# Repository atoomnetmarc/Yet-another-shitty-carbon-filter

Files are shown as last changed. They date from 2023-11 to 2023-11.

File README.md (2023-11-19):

Voron Trident, mounted lower left on the 2020 extrusion:
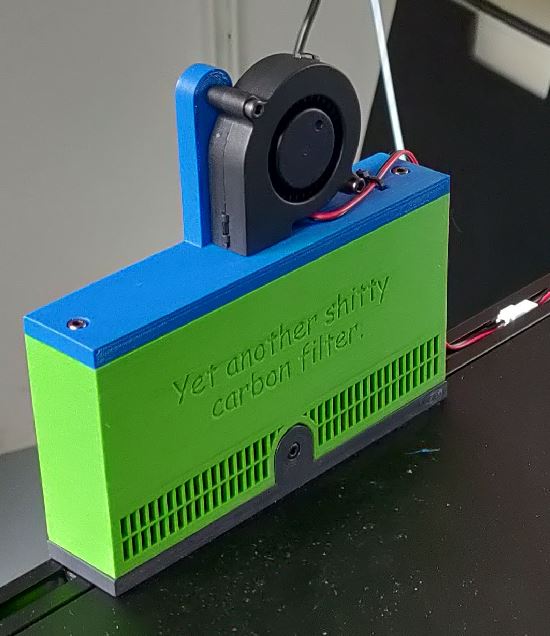
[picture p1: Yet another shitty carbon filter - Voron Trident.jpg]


Ultimaker 2, mounted lower right on 2 preexisting holes on the bottom plate:
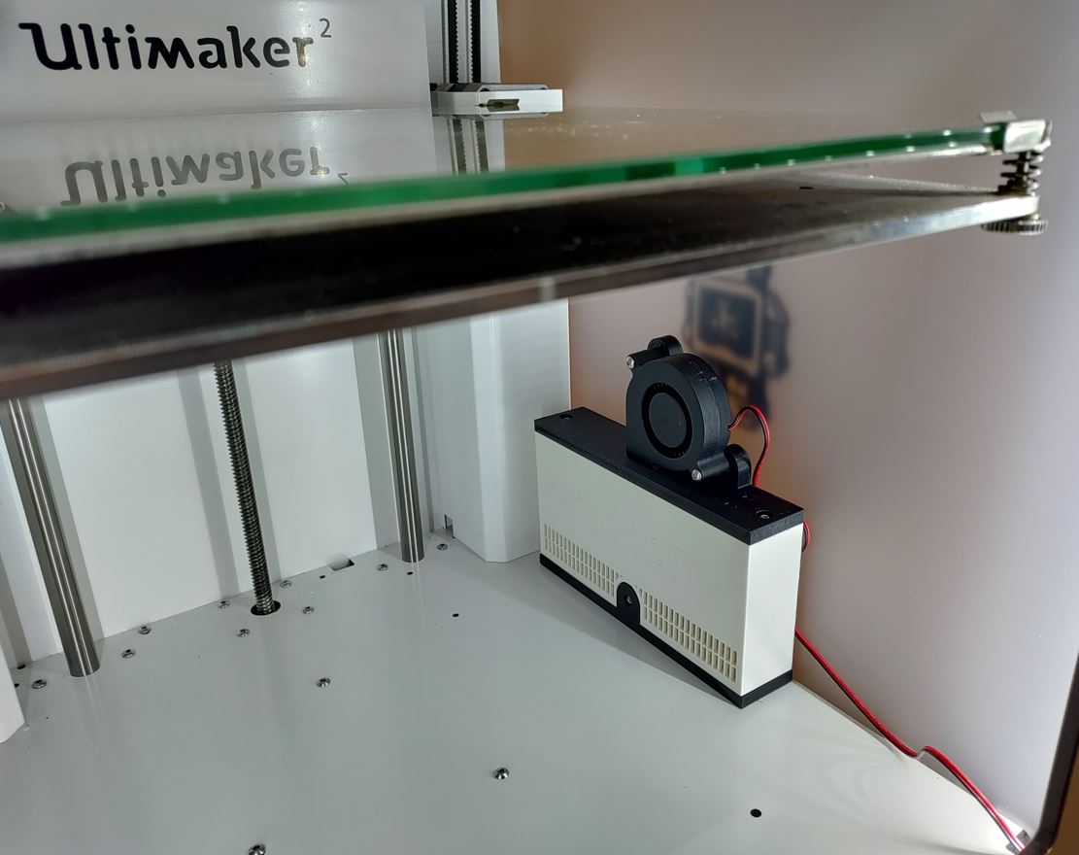
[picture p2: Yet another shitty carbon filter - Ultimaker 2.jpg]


# Why yet another design?

I tried printing the famous [Nevermore Micro V6](https://github.com/nevermore3d/Nevermore_Micro), it ended up in frustration with parts that broke multiple times during assembly (jalousie) or did not fit (lid). I decided to design my own shitty carbon filter.

# Dimensions

I designed this air filter to be used standing up on the lower bottom side of my Voron V0, Voron Trident and Ultimaker 2.

# Print and assembly instructions

Print in a material that withstands the temperature at which the filter will be used. I printed mine in ASA. No supports needed. If you have a color theme on your printer you may print the body in the base color and the mount and lid in the accent color. For the Ultimaker you could print the body in white and the other parts in black.

Print one of the mounting brackets:

- `Yet another shitty carbon filter - 1515 mount.stl`
- `Yet another shitty carbon filter - 2020 mount.stl`
- `Yet another shitty carbon filter - Ultimaker 2 mount.stl`

The 2 screw holes for the 1515 and 2020 mount that connect to the extrusion will fit M3x8 (FHCS, BHCS, pan head). Use M3 t-nut or similar for in your aluminium extrusion.

The [Ultimaker 2 mount needs 2 heat set inserts](Yet%20another%20shitty%20carbon%20filter%20-%20Ultimaker%202%20mount%20-%20showing%20heat%20set%20inserts.jpg). Then screw with 2x M3x10 (or M3x12) from [below the bottom panel on the lower right](Yet%20another%20shitty%20carbon%20filter%20-%20Ultimaker%202%20mount%20-%20mounted.jpg).

Print `Yet another shitty carbon filter - body.stl`. You may want to use a brim if lifting is a problem. Slight lifting is not a problem. Do you have a multi material unit or multi extruder? Then print `Yet another shitty carbon filter - body - text (MMU).stl` at the same time as the body but configure it to print in the accent color.

Melt 2 heat set inserts M3x5x4mm into the holes they fit in:

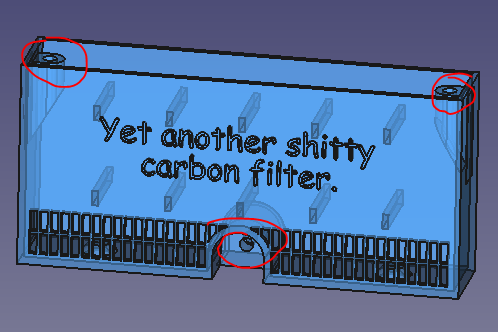
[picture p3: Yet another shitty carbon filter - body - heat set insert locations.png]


Use a single M3x16 (up to M3x27) to screw the mount to the body:

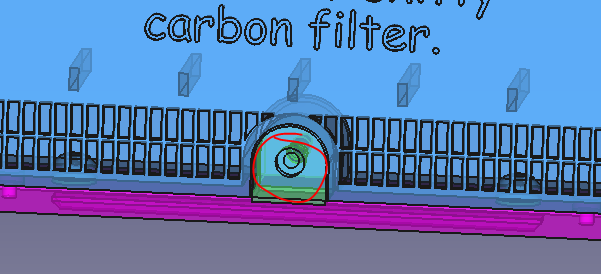
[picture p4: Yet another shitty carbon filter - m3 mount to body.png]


Print `Yet another shitty carbon filter - lid with 5015 fan.stl`.

Melt 2 heat set inserts M3x5x4mm into the holes they fit in:
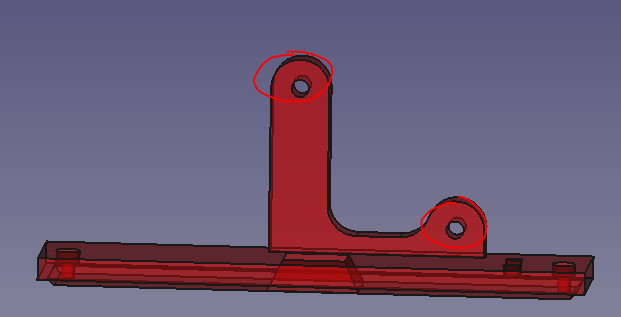
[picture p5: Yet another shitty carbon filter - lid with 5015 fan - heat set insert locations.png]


You can use 2 M3x8 (up to M3x65) screws to mount the lid to the body. Use 2 M3x20 (up to M3x22) to mount a 5015 blower fan to the lid.

# Electronics

Use your skills to connect the 5015 blower fan to whatever fitting power source. On the Voron Trident I used a 24V 5015 blower fan connected to the 3d-printer motherboard. I added an inline connector for easy disassembly. I then configured it in klipper as a `controller_fan` like this:

```ini
[controller_fan carbon_filter]
##  yet another shitty carbon filter - FAN3
pin: PD13
max_power: 1.0
shutdown_speed: 0.0
kick_start_time: 5.0
heater: extruder
fan_speed: 0.75
idle_timeout: 900
```

Customize `pin` to the real pin you use.

For the Ultimaker 2 3d printer you are on your own. I have modified mine with a custom motherboard so I cannot help you with yours. However, you could possibly use the second heater output. Maybe the simplest solution is to use a physical switch connected to the 24V power supply behind the relay on the board.

There is a slot in the lid to thread a ty-rap through, use it to add strain relief to for the wires to the fan:
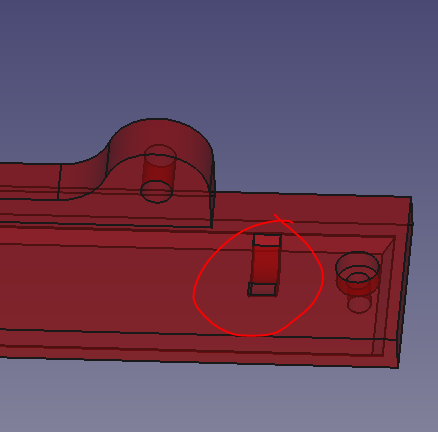
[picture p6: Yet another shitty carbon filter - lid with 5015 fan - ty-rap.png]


# Activated carbon

The ventilation holes at the air outlet on the body where designed to mostly contain 4mm activated carbon. The holes are 2mm higher than the bottom of the body so that carbon dust can settle there.

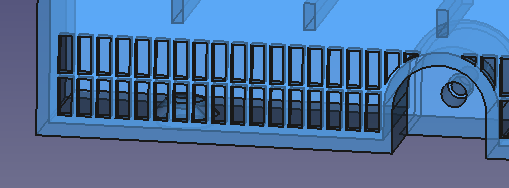
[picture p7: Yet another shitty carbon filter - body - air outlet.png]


I filled my shitty carbon filter with non-acidic activated 4mm carbon pellets that I ordered from a local aquarium store. Fill the filter body up to the top most inner supports, which is about 1cm from the top.

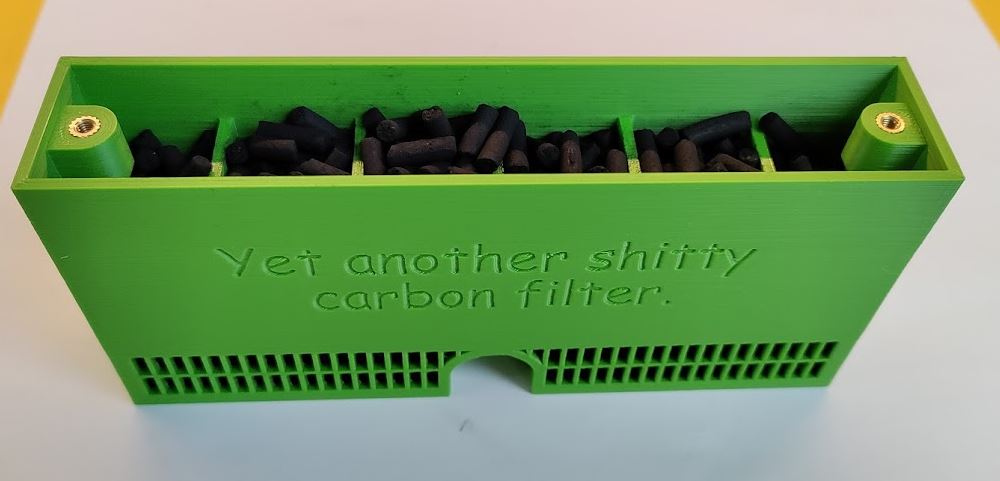
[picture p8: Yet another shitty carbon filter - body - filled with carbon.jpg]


I print mainly with ASA which smells bad during printing. When the shitty carbon filter is no longer able to remove the smell I replace the carbon pellets. The [Nevermore github repository](https://github.com/nevermore3d/Nevermore_Micro) has an interesting read about VOCs.



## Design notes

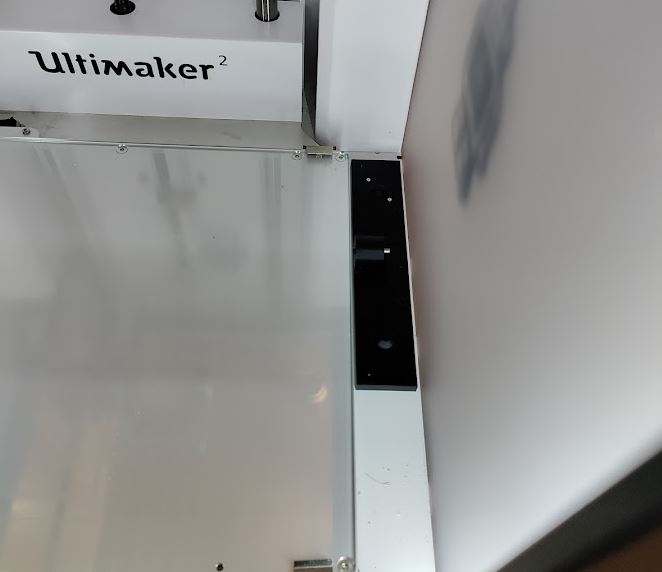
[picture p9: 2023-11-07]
Yet another shitty carbon filter - Ultimaker 2 mount - mounted.jpg

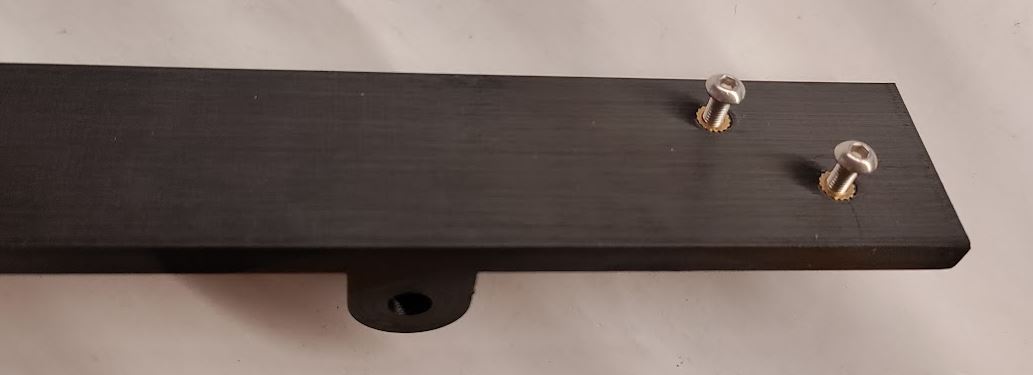
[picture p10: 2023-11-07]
Yet another shitty carbon filter - Ultimaker 2 mount - showing heat set inserts.jpg

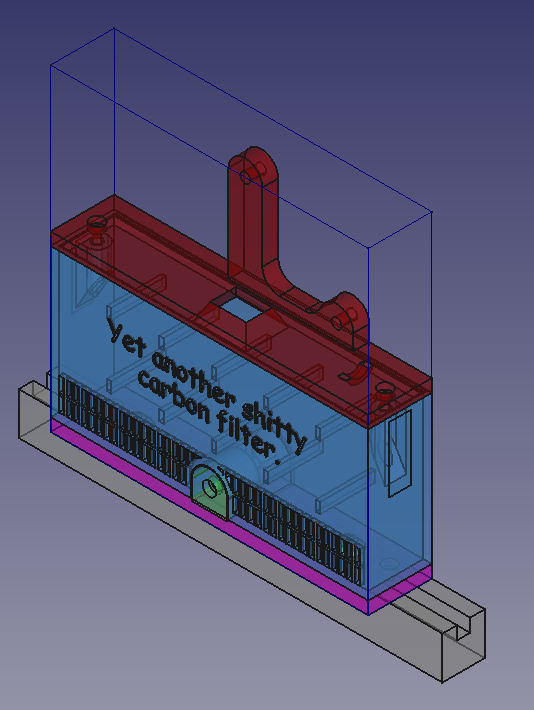
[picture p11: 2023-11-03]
Yet another shitty carbon filter.png

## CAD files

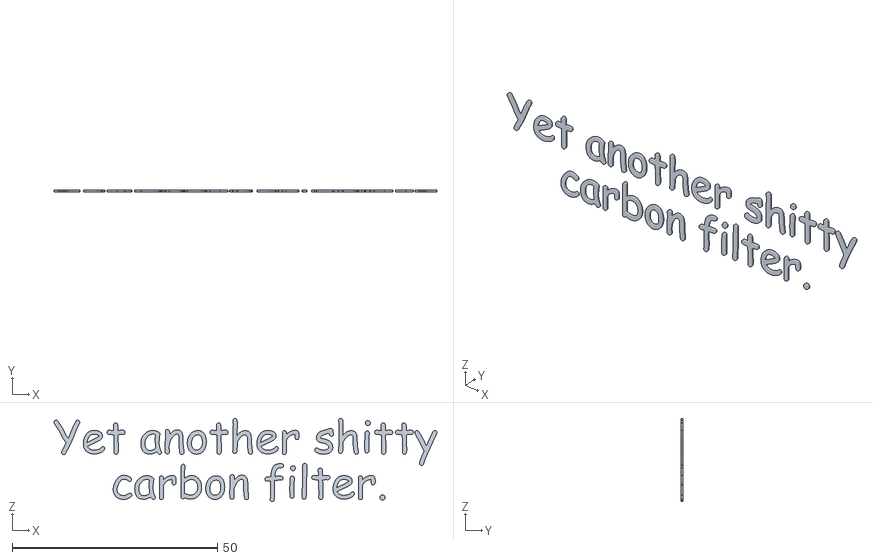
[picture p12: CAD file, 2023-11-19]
Yet another shitty carbon filter - body - text (MMU).stl
93.2 x 0.5 x 20.2

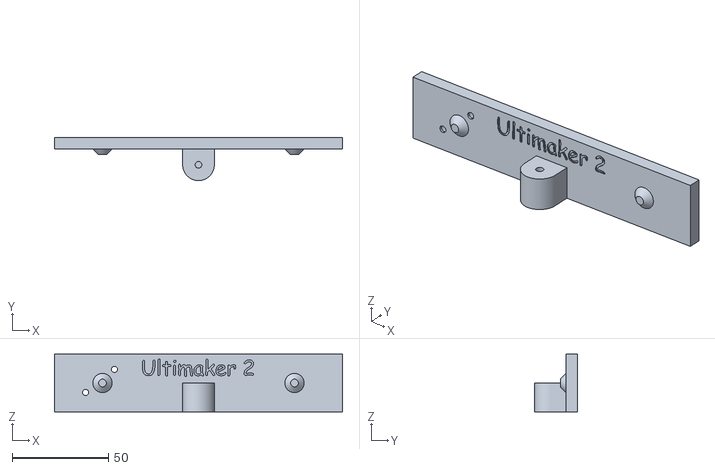
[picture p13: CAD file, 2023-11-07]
Yet another shitty carbon filter - Ultimaker 2 mount.stl
150.0 x 22.5 x 30.0

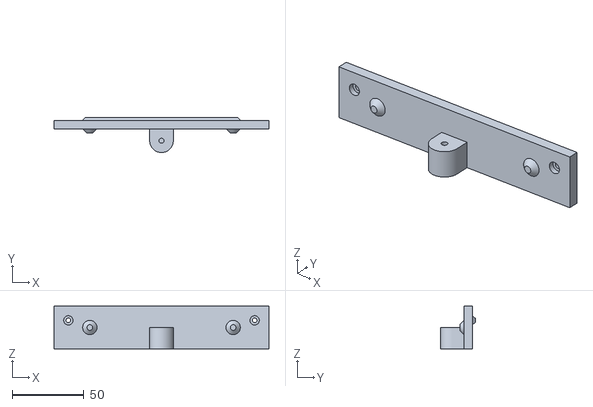
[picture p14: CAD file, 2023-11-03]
Yet another shitty carbon filter - 2020 mount.stl
150.0 x 24.5 x 30.0

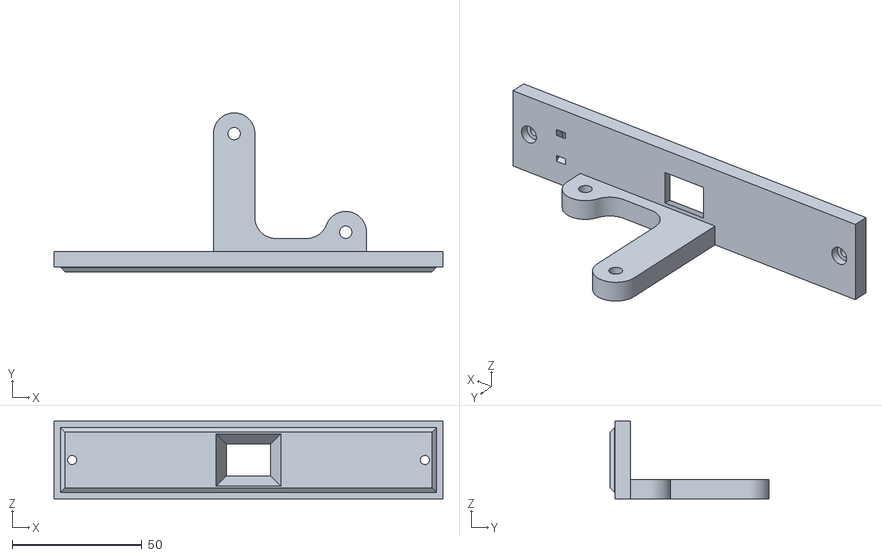
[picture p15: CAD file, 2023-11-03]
Yet another shitty carbon filter - lid with 5015 fan.stl
150.0 x 61.4 x 30.0

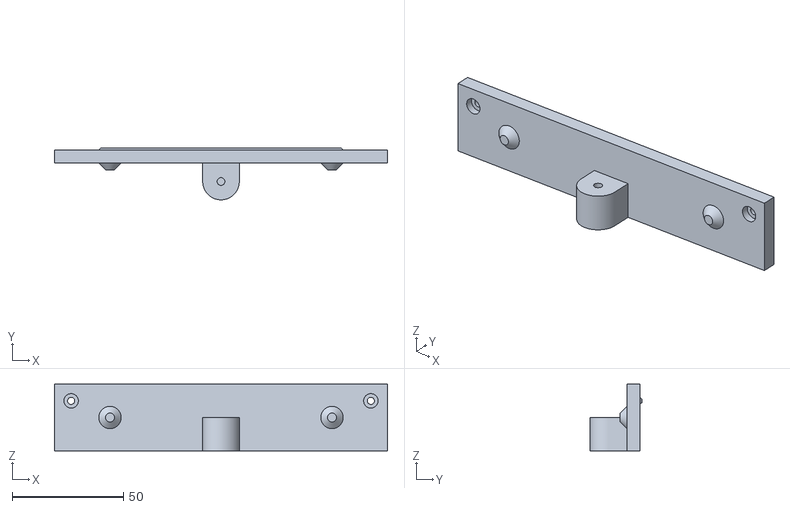
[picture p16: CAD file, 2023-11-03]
Yet another shitty carbon filter - 1515 mount.stl
150.0 x 23.3 x 30.0

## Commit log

2023-11-03 Initial commit.
    [Yet another shitty carbon filter - 1515 mount.stl, Yet another shitty carbon filter - 2020 mount.stl, Yet another shitty carbon filter - lid with 5015 fan.stl]
2023-11-03 Add photos of printed design.
2023-11-03 Add klipper config example.
2023-11-07 Now available with Ultimaker 2 mount.
    [Yet another shitty carbon filter - Ultimaker 2 mount.stl]
2023-11-19 Add optional body text for multi extruder.
    [Yet another shitty carbon filter - body - text (MMU).stl]

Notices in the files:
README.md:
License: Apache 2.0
